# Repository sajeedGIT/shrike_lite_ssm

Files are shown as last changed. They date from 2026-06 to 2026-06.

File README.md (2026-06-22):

# Shrike 

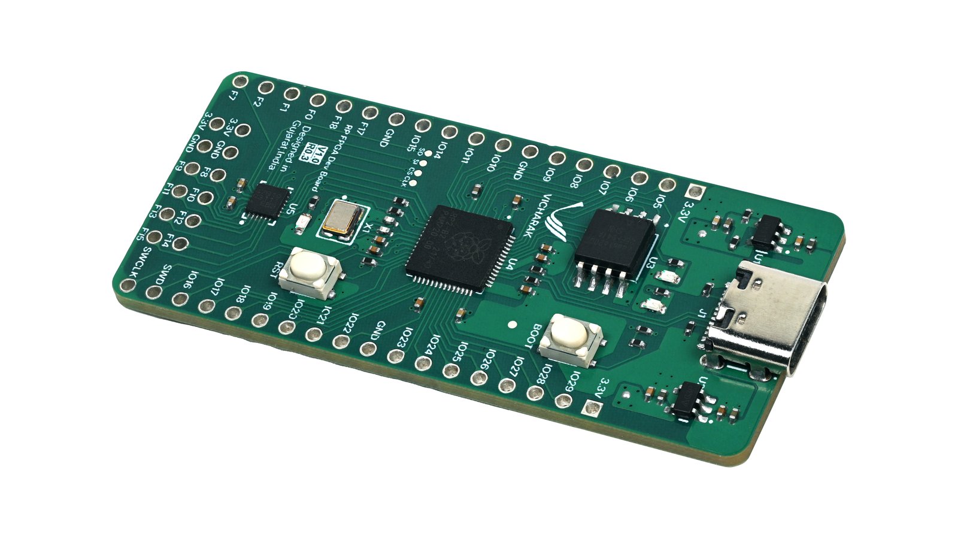
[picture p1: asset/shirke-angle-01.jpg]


Shrike is a family of low cost affordable FPGA development board along with a host microcontroller. 
Currently the family features these two members -: 

1. Shrike-lite (FPGA with RP2040) 
2. Shrike      (FPGA with RP2350)
3. Shrike-fi   (FPGA with ESP32-S3) 

And a lot version under development.

We usually work on very complex FPGA-based projects built around [Vaaman](https://vicharak.in/vaaman) and its upcoming series. However, Shrike is a passion project at Vicharak, driven by our love for engineering across both embedded microcontrollers and FPGAs.

Our goal is to make FPGAs accessible to everyone by offering robust toolchains, high-quality hardware, and strong ecosystem support. We’re committed to keeping the hardware prices extremely low, and every piece of software for Shrike will be completely open-source.

We at vicharak have kept in mind need of a learner, maker and a hobbyist while designing this art. This dev board will be your stepping stone in the field of FPGA, reconfigurable and heterogenous computing.

We invite contributors from all over the world to join us in this mission. Together, let’s make FPGA technology truly accessible to all. 

### Get the Hardware 

Shrike-lite the RP2040 version of the family is available at our store for worldwide shipping and the Shrike RP2350 version will be available on the crowdsupply soon. You can follow the links below to get both.

#### 1. [Shrike-lite](https://store.vicharak.in/?product=shrike&post_type=product&name=shrike&v=13b5bfe96f3e)

#### 2. [Shrike](https://www.crowdsupply.com/vicharak/shrike)

#### 3. [Shrike-fi](https://store.vicharak.in/?product=v002743)

### Board level Block Diagram

<div align="center">

shrike

</div>

### Key Features : 

| **Feature** | **Shrike** | **Shrike-lite** |**Shrike-fi** |
|:---:|:---:|:---:|:---:|
| FPGA | 1120 × 5-input LUTs | 1120 × 5-input LUTs | 1120 × 5-input LUTs|
| MCU | RP2350 | RP2040 | ESP32-S3 |
| PMOD Compatible Connector | ✅ | ✅ | ✅ |
| Breadboard Compatible | ✅ | ✅ | ✅ |
| FPGA ↔ MCU IO Interface | ✅ | ✅ | ✅ |  
| Flash (QSPI) | 4 MB | 4 MB | 8 MB |
| User LEDs | 2 | 2 | 2 |
| USB Type-C (Power & Programming) | ✅ | ✅ | ✅ |
| WiFi | ❌ | ❌ | ✅ |
| BLE | ❌ | ❌ | ✅ |
| Optional Add-on Features |
| PSRAM (QSPI) ( Optional ) | ❌ | ❌ | Upto 8 MB |
| BMS On Board ( Optional ) | ❌ | ❌ | ✅ | 

#### **Note**

The optional add on for the Shrike-fi are not soldered in the base version , board version with these part soldered will be launched at later date.
However you can solder them yourself in the base version as well read more [here](https://vicharak-in.github.io/shrike/hardware_overview.html#shrike-hardware-overview).

### Check out 
 1. [Documentation](https://vicharak-in.github.io/shrike/index.html)
 2. [Pin_outs](https://vicharak-in.github.io/shrike/shrike_pinouts.html)
 3. [FPGA_CPU_Interconnect](https://vicharak-in.github.io/shrike/shrike_pinouts.html#fpga-rp2040-communication-pin-outs)

## 📫 Join our communities at :
  
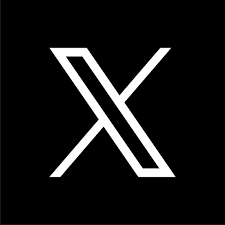
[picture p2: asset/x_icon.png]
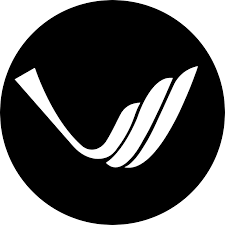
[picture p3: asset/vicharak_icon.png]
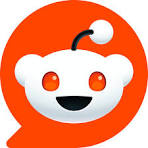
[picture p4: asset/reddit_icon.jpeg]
   [](https://discord.com/invite/EhQy97CQ9G)  &nbsp; [](https://x.com/Vicharak_In)  &nbsp; [](https://discuss.vicharak.in/)  &nbsp; [](https://www.linkedin.com/company/vicharak-in)  &nbsp; [](https://www.reddit.com/r/Vicharak/)  &nbsp;

### Note
 
We are building a ecosystem for learners , makers and hobbyist around shrike and the projects that will follow in future, thus we request you contribution in the same. Join our communities across all the platforms, pitch and showcase your ideas with Shrike. 

Thank You 

## Contribution Guideline  

Your contribution to the Shrike project are always welcome.
To contribute fork the project test your changes and create a PR. Few things in to keep in mind for better contribution. 
Please read the Contribution [Guide](./CONTRIBUTING.md) to know them.

### What to contribute ? 

You can contribute the project's and example's that you have designed on Shrike or any utils that you might have designed.

We also have live bounty from time to time check it [here](./bounty.md) 

## LICENSE 

### Software

This project’s software is licensed under the GNU General Public License v2.0 (GPL-2.0).
See the [LICENSE](./LICENSE.md)for details.

### Hardware

This project’s hardware designs (HDL/RTL, schematics, PCB files, constraints, etc.) are licensed under the CERN Open Hardware License v1.2.
See [LICENSE_HW](./LICENSE_HW.md) for details.

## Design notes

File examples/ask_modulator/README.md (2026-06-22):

# ask_modulator

**Difficulty:** Advanced

**Uses MCU:** Yes

**External Hardware:** RC Filter (1 kΩ Resistor, 10 nF Capacitor), Oscilloscope (optional)

## Overview

This example implements a mixed-signal Digital-to-Analog communication system using the Shrike board. The FPGA generates a sine wave using Direct Digital Synthesis (DDS), converts it into a PWM signal, and modulates it using Amplitude Shift Keying (ASK) controlled by the RP2040. You will learn DDS, PWM-based DAC techniques, and FPGA–MCU co-design for communication systems.

## Compatibility

| Board | Firmware | Status |
| --- | --- | --- |
| Shrike-Lite (RP2040) | `firmware/micropython/` | ✅ Tested |
| Shrike (RP2350) | `firmware/micropython/` | ✅ Tested |
| Shrike-fi (ESP32-S3) | `firmware/micropython/` | ⬜ Untested |

> FPGA bitstream is the same across all boards.

## Hardware Setup

### RC Filter (Required for Analog Output)

The FPGA outputs a high-frequency PWM signal. An RC low-pass filter is required to reconstruct the analog sine wave.

* Resistor: 1 kΩ
* Capacitor: 10 nF (Code 103)
* Cutoff Frequency: ~15.9 kHz

**Connection:**

* FPGA Output → Resistor → Output Node
* Capacitor from Output Node → Ground
* Probe at Output Node

### Pin Connections

| Signal | RP2040 Pin | FPGA Pin (Board Label) | Physical Pin |
| --- | --- | --- | --- |
| Freq Bit 0 (LSB) | GPIO 5 | FPGA_IO1 | PIN 14 |
| Freq Bit 1 | GPIO 6 | FPGA_IO2 | PIN 15 |
| Freq Bit 2 | GPIO 7 | FPGA_IO17 | PIN 8 |
| Freq Bit 3 | GPIO 8 | FPGA_IO18 | PIN 9 |
| Freq Bit 4 | GPIO 9 | FPGA_IO8 | PIN 23 |
| Freq Bit 5 (MSB) | GPIO 10 | FPGA_IO9 | PIN 24 |
| Data / Enable | GPIO 16 | FPGA_IO0 | PIN 13 |
| PWM Output | — | FPGA_IO14 | PIN 5 |

> Ensure common ground between RP2040 and FPGA.

## Quick Start (Pre-Built Bitstream)

1. Generate and upload the FPGA bitstream
2. Copy `flash.py` and `helloshrike.py` to the RP2040
3. Run `flash.py` once to configure FPGA
4. Run `helloshrike.py`
5. Observe PWM output on FPGA_IO14 using an oscilloscope

Expected result: Bursts of sine waves representing transmitted data using ASK modulation

## Build From Source

### FPGA (Verilog)

1. Open project in Go Configure Software Hub
2. Select FPGA part `SLG47910V (Rev BB)`
3. Paste Verilog into `main.v`
4. Configure I/O Planner and generate bitstream

### Firmware (MicroPython)

1. Open `flash.py` and `helloshrike.py` in Thonny
2. Upload to RP2040
3. Run scripts

## How It Works

The FPGA implements a DDS-based signal generator with three main components:

1. **Phase Accumulator:**
   A 16-bit counter incremented by a tuning word each clock cycle. This determines output frequency.

2. **Sine LUT:**
   A 64-entry lookup table mapping phase to amplitude (0–63), generating a sine waveform.

3. **PWM Generator:**
   Converts amplitude into a 1-bit PWM signal (~781 kHz switching frequency).

ASK modulation is applied at output:

* `i_data = 1` → sine wave transmitted
* `i_data = 0` → output forced to zero

The RP2040:

* Sends frequency tuning word (6-bit parallel bus)
* Controls modulation signal
* Encodes characters using a custom 6-bit encoding scheme

### Key Equations

* PWM Frequency:
  `50 MHz / 64 ≈ 781.25 kHz`

* Output Frequency:
  `F_out = (F_clk × TW) / 2^16`

* Example:
  `TW = 1 → ~762 Hz`

## Expected Output

### Oscilloscope Output

* Logic 1 → Sine wave (~3V peak)
* Logic 0 → Flat line (0V)

Signal appears as bursts of sine waves separated by silence.

### Terminal Output

```
--- Transmitting: HelloShrike123 ---
Sending 'H' -> Code 01 -> 000001
Sending 'e' -> Code 02 -> 000010
Sending 'l' -> Code 03 -> 000011
Sending 'l' -> Code 03 -> 000011
Sending 'o' -> Code 04 -> 000100
Sending 'S' -> Code 05 -> 000101
Sending 'h' -> Code 06 -> 000110
Sending 'r' -> Code 07 -> 000111
Sending 'i' -> Code 08 -> 001000
Sending 'k' -> Code 09 -> 001001
Sending 'e' -> Code 02 -> 000010
Sending '1' -> Code 51 -> 110011
Sending '2' -> Code 52 -> 110100
Sending '3' -> Code 53 -> 110101
```

The waveform corresponds to encoded binary data transmitted via ASK.

## Notes

* Noise on FPGA GPIO inputs may be interpreted as logic high
* External pull-ups are not strictly required in this setup
* Full ASCII support can be implemented by extending encoding (exercise for user)

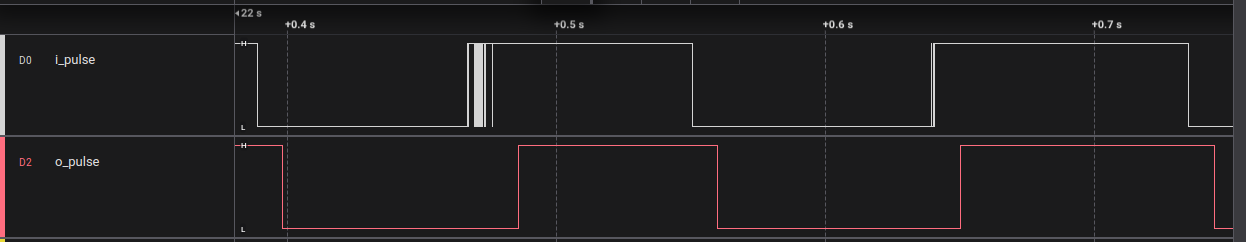
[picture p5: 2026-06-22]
examples/button_debouncer/ffpga/images/debouncer_output.png

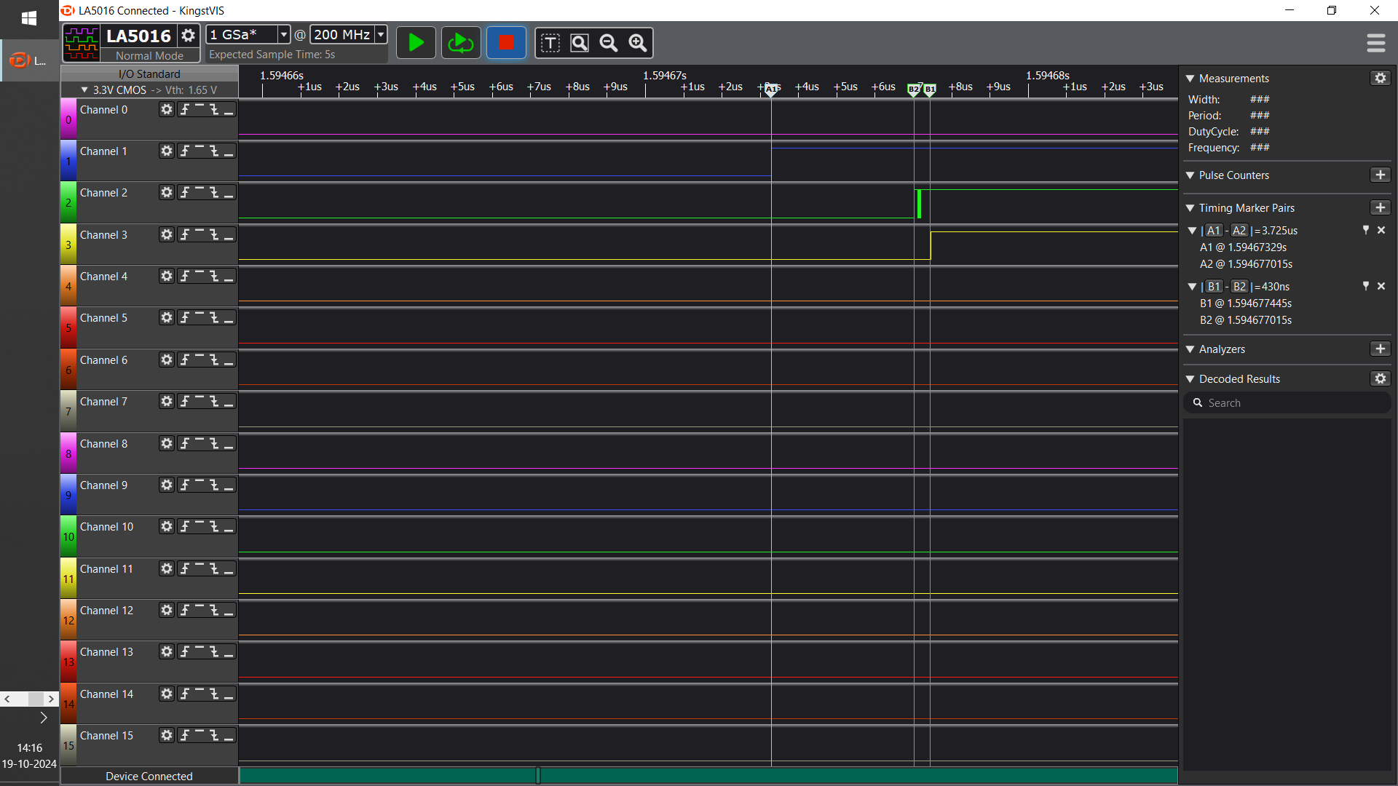
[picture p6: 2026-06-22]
docs/images/Screenshot (1320).png

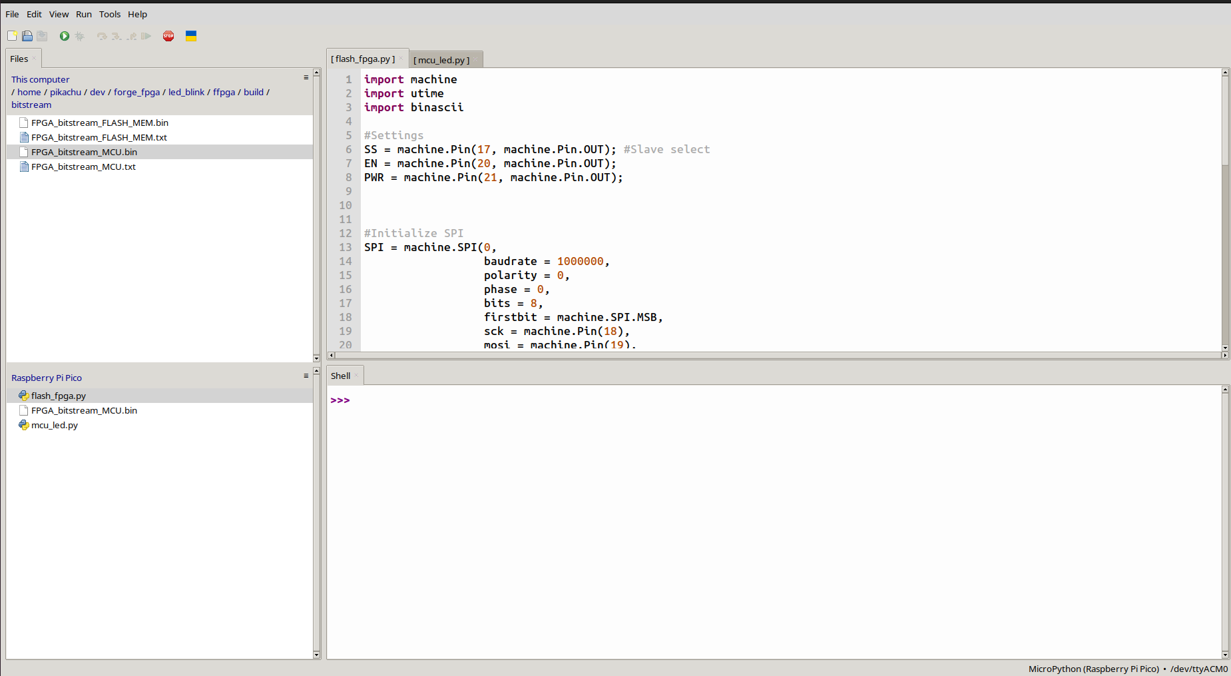
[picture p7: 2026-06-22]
docs/images/file_view.png

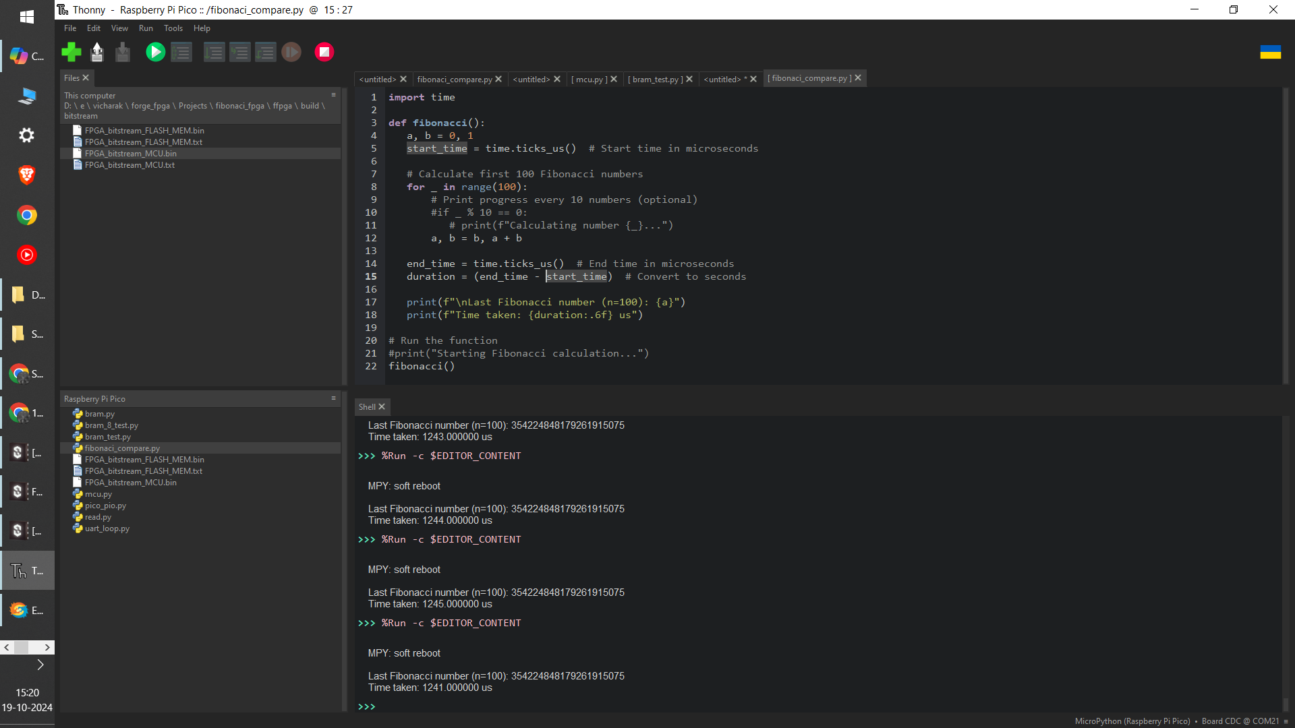
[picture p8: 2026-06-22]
docs/images/image.png

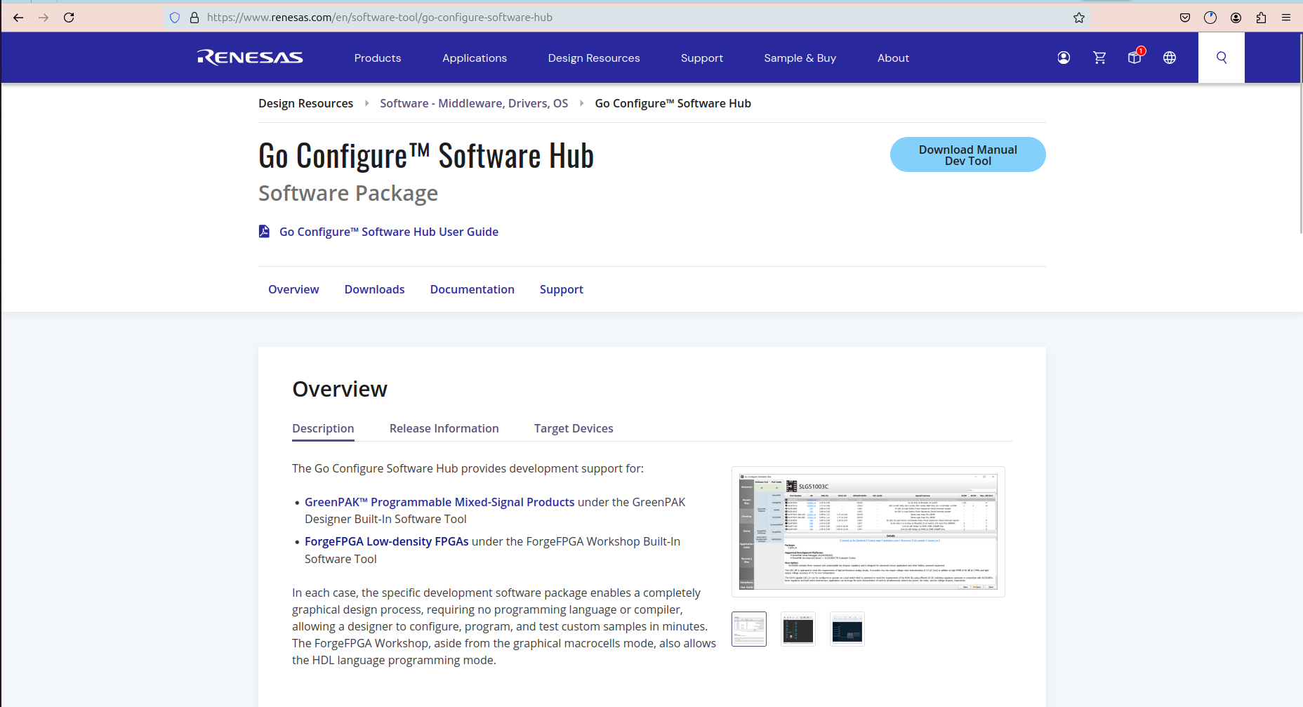
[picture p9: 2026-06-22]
docs/images/software.png

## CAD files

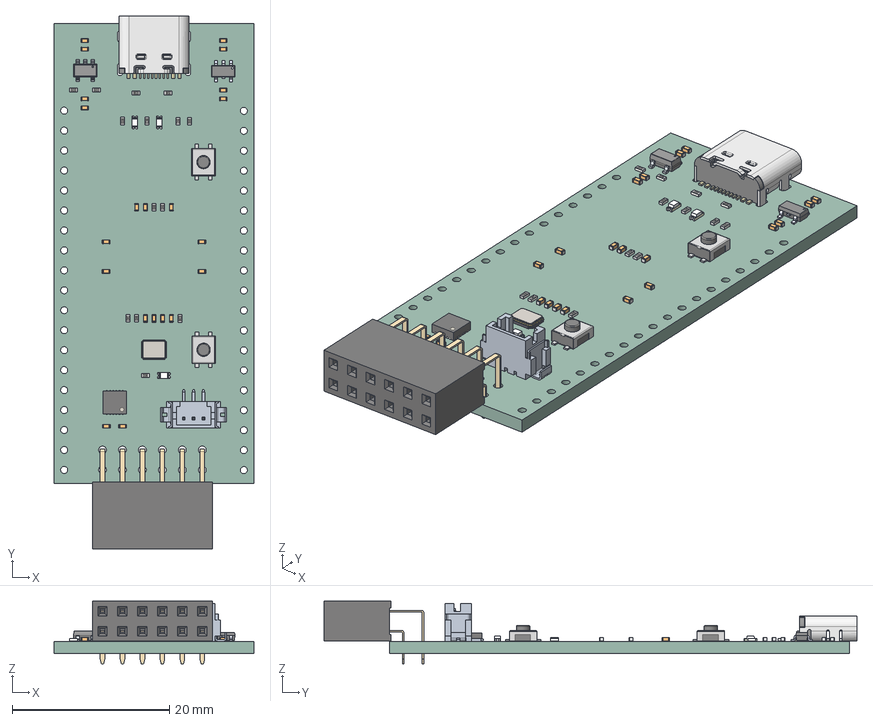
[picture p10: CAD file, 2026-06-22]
hardware/shrike-lite/kicad/v1_r0.4/Shrike-lite.step
25.4 x 67.8 x 7.98 mm
kicad_embedded_BCDEFA549BD92648B89B079BD65F0360 x 3
kicad_embedded_4BF2C315065B03F2EDB6664BF6E06EBC x 14
PinsArrayL
PinsArrayR
Shrike-lite 1.18.1
kicad_embedded_23D3BBCB113E4F12280F49A9A7372AAE
kicad_embedded_5DA03CE9F3160850AF560ED0F9C2898B
kicad_embedded_72BB9CE2D1522D823768491D5397E6AB x 2
kicad_embedded_29C47ED5F14A361E81E1A38E2F171F89
kicad_embedded_BBED6F8B535C06F9EA1D5AD73DD78B29
ConPins
PcbPins
Mold
Frame
Shrike-lite_PCB

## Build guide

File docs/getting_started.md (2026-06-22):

(getting_started)=

# Getting Started

In this getting started guide we will see how to blink an led on shrike both on fpga and MCU.

You can program the microcontroller on Shrike using three methods:<br>

&emsp;**1. Arduino (C/C++)**  
&emsp;**2. MicroPython**
&emsp;**3. Circuit-Python**

All are beginner-friendly, and you can switch between them anytime.  

Let's follow the steps and get Shrike up and running!

:::::::{tab-set}

::::::{tab-item} ArduinoIDE

# Shrike with ArduinoIDE

If you already know Arduino and love working with the Arduino IDE, you can continue using it with Shrike. You do not have to switch to MicroPython unless you want to.

We will follow these steps to setup our arduino IDE for shrike. If you don't have arduino IDE already ,you can download it from [here](https://www.arduino.cc/en/software/) or if you are using linux(ubuntu)then just run 
```
sudo apt install arduino
```

### Step 1. Adding the board support for Shrike

The Shrike has a on board RP2040/RP2350/ESP32-S3 has a host controller the Arduino IDE doesn't native support them however we can add the board support for the same.

It is quit straight forward we need to add this URL in the addition board URL section of arduino IDE which you can find in File->Preferences.

:::::{tab-set}

::::{tab-item} Shrike/Shrike-lite
:sync: Shrike/Shrike-lite

```
https://github.com/earlephilhower/arduino-pico/releases/download/global/package_rp2040_index.json
``` 

::::

::::{tab-item} Shrike-fi
:sync: Shrike-fi

```
https://raw.githubusercontent.com/espressif/arduino-esp32/gh-pages/package_esp32_index.json
``` 

::::

:::::

If you already have another board URL just add a "," between the two URL's.

<div align="center">

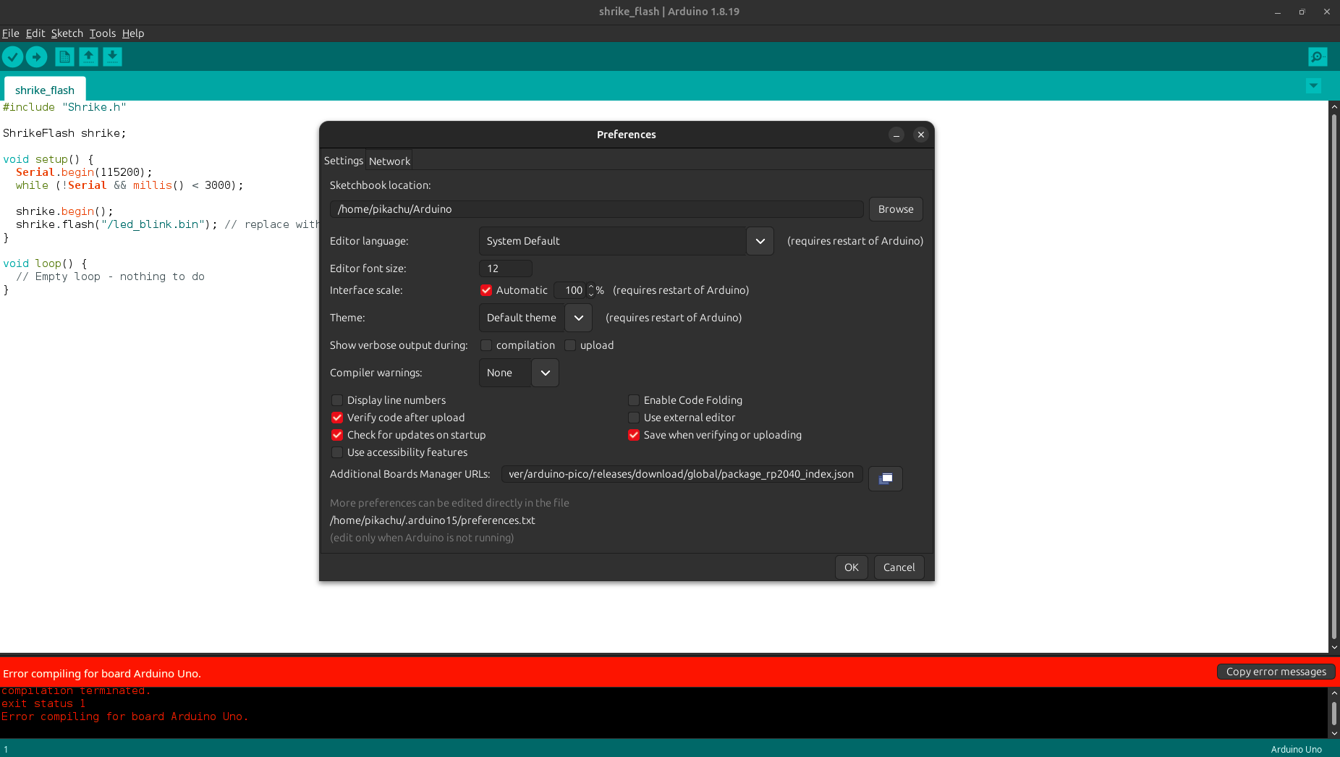
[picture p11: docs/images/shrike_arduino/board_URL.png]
ADD BOARD URL
 

</div>

These board support had been created by [earlephilhower](https://github.com/earlephilhower) and you can check out github [repository](https://github.com/earlephilhower/arduino-pico) for more details.

After adding the URL go to Tools->Boards->Board Manager in the Arduino IDE. 

:::::{tab-set}

::::{tab-item} Shrike/Shrike-lite
:sync: Shrike/Shrike-lite

Then search for pico and the board from Earle F. Philhower. 

<div align="center">

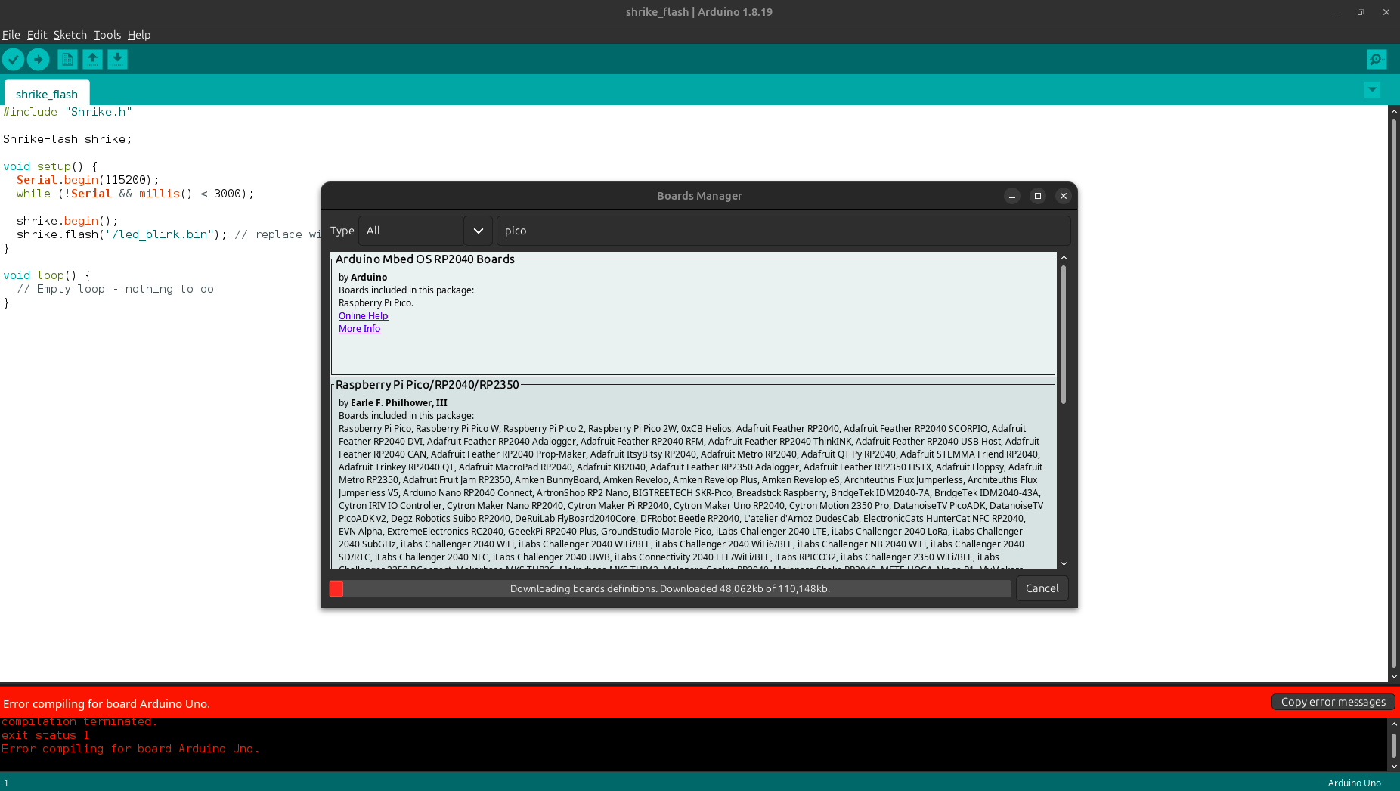
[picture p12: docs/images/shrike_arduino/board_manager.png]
ADD BOARD
 

</div>

::::

::::{tab-item} Shrike-fi
:sync: Shrike-fi

Then search for ESP32 by Espressif Systems.

<!-- TODO: Add board manager image for ESP32. -->

::::

:::::

Perfect we have successfully add the board support for the Shrike.

As we discussed earlier, in Shrike the micro-controller (RP/ESP32) is responsible for configuring the FPGA.  

To make this possible, we developed a simple mechanism: we store the FPGA bit-streams in the MCU's flash memory and retrieve them whenever we need to configure the FPGA. To do this we will need to use a file system called littleFS.

### Step 2. Adding the LittleFS Tool

The LittleFS library in Arduino allows you to store, load, and update the bitstream in the flash memory through the microcontroller.

We need to add a Little-FS utility to bind a bin file (FPGA bitstream with code for Shrike). We can find the utility [here](https://github.com/earlephilhower/arduino-littlefs-upload/releases) download the latest release ZIP. 

Now for setting up these tools for Arduino IDE version 2.x.x please follow [this](https://randomnerdtutorials.com/arduino-ide-2-install-esp32-littlefs/) guide and after proper setup please continue the below steps. 

This works for both the RP2040 and ESP32-S3 based boards. ( even tho name says esp32).

You will need to restart the Arduino IDE and you should see the Little FS tool like this in your Tools menu.

<!-- TODO: Update this image. -->

For more details on the LittleFS tool checkout this [repository](https://github.com/earlephilhower/arduino-littlefs-upload).

### Step 3. Installing the Shrike Library 

The Arduino library developed by Vicharak takes care of configuring the FPGA for you. You can install it directly from the Arduino IDE's Library Manager, just search for **"Shrike"** and install the **Shrike** library.

<!-- TODO: Update this image --> 

<div align="center">

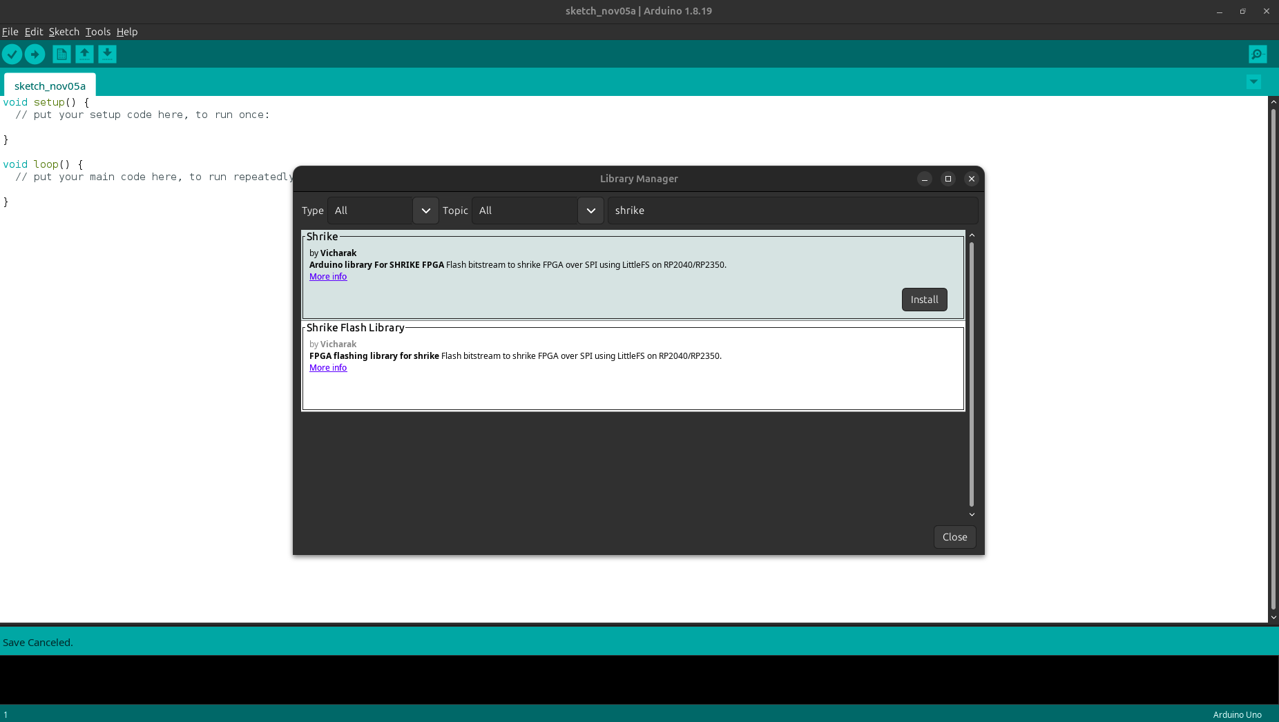
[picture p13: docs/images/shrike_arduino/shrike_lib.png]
ADD SHRIKE lib
 

</div>

We are almost done with the setup lets continue and blink en led on FPGA using the arduino IDE. 

### Step 4. Programming the FPGA from ArduinoIDE

Lets program out first bitstream to fpga using the arduino. We will be blinking an led.

Start Arduino IDE and look for Shrike -> shrike_flash in the example section of IDE and then save it with a name of your choice and at a location of your choice. This will create a folder with the name, now in the folder/dir create a subfolder by name `data` keep the case in mind. 

Any bitstream that needs to be uploaded to the board should be placed in the folder. 
We have already generated and hosted a bitstream to blink led [here](https://github.com/vicharak-in/shrike/blob/main/test/bitstreams/v1_4/led_blink.bin) save this bitstream to the data subfolder.

Checkout guide to learn how to generate your own fpga design [here](./generating_your_first_bitstream.md).

Once you have done this, open Arduino IDE and click on Compile. The compilation should complete without any errors. If you encounter any errors, don't worry,we have a Discord community. Hop in there and we'll help you out or you can always use claude or chatgpt.

If the compilation has been done without any error then it's time to connect the board in boot mode " PRESS THE BOOT BUTTON WHILE CONNECTING THE BOARD WITH PC" ( this should be done only the first time of setting up if arduino are if you have programmed the board with any other way last time).

:::::{tab-set}

::::{tab-item} Shrike/Shrike-lite
:sync: Shrike/Shrike-lite

In the tools section select the Board as VICHARAK Shrike Lite / VICHARAK Shrike based on your board version and flash size as 4MB Sketch:2MB and FS:2MB and CPU Speed as 125 Mhz. 

::::

::::{tab-item} Shrike-fi
:sync: Shrike-fi

In the tools section select the Board as Generic ESP32-S3 based on your board version and flash size as 8MB Sketch:4MB and FS:4MB . 

::::

:::::
Now you need to upload the file system to the board to do so press `ctrl+shift+p` you will see the drop down menu.

Search for Build LittleFS command and run it. 

After that in the same menu look for Upload LittleFS command and run that too. 

If both of these options are executed properly then then hit upload. 

You should see the beautiful blue led blinking on board.

Congratulation you have your arduino IDE and shrike ready to be programmed using the Arduino infrastructure. 

> Credit and Gratitude to [earlephilhower](https://github.com/earlephilhower/) for creating the board support for RP2040/RP2350 in ArduinoIDE and the little FS tool. 

<!-- 
For shrike Lite

:::::{tab-set}

::::{tab-item} Shrike/Shrike-lite
:sync: Shrike/Shrike-lite

Blehhhh Shrike-lite

::::

::::{tab-item} Shrike-fi
:sync: Shrike-fi

Blehh Shrike-fi

::::

:::::

-->

::::::

::::::{tab-item} Micro-python 

# Shrike with Micro-python 

We have created custom binary for shrike this contains a shrike.py library that has custom function to flash fpga and few other functions as well.

### 1. Uploading the shrike binary

:::::{tab-set}

::::{tab-item} Shrike/Shrike-lite
:sync: Shrike/Shrike-lite

1. Download the binary corresponding to your board version from the shrike's [Releases](https://github.com/vicharak-in/shrike/releases/)
2. Hold the boot button on the board and connect it the your pc now shrike will show up as as storage device.
3. Copy the downloaded uf2 in storage device you can simply drag and drop in mostly all the devices. 
4. After the successful copying the storage device should disappear.

Check the video tutorial on how to upload the uf2 Shrike dev board(its a generic board video and uf2 will differ in our case) [here](https://www.youtube.com/watch?v=os4mv_8jWfU).

Congratulations you have successfully uploaded the uf2. 

#### Shrike Mass Storage Device 

Onces that you have copied the uf2 to the Shrike.  The board will disconnect momentary and so up as both a mass storage device and tty/ACM device now the mass storage is the part where you would need to save you bitstream (read step 3). 

The default device ID for mass storage device is `5221-0000` this could be changed as per your choice. 
For windows simply right click and rename for changing the name in linux read [this](https://superuser.com/questions/223527/renaming-a-fat16-volume). 

::::

::::{tab-item} Shrike-fi
:sync: Shrike-fi

1. Download the binary corresponding to your board version from the shrike's [Releases](https://github.com/vicharak-in/shrike/releases/).

2. Install the ESP tools `pip install esptool`. 
    You might need to activate a python virtual environment. Check this guide to know how to do so. 

3. Then execute  this command `python -m esptool erase_flash`

4. And Flash the binary to ESP32-S3 using this command 

```
python -m esptool --chip esp32s3 -b 460800 --before default_reset --after hard_reset write_flash --flash_mode dio --flash_size 4MB --flash_freq 80m 0x0 firmware.bin
```

---

Congratulations you have successfully uploaded the binary. 

::::

:::::

### 2. Get the bitstream(.bin) for led blink 

To program a FPGA you will require  bitstream file this is much like a firmware for MCU's we will see how to generate these but for now we have uploaded the bitstream required for led_bin you can download them the corresponding to your board's version [here](https://github.com/vicharak-in/shrike/tree/main/test/bitstreams). 

Now that you have both uf2 and bin file settled up lets move forward and upload the bitstream to board.

### 3. Getting the Thonny IDE 

The bitstream can be uploaded on the shrike using one of these two ways 
   1. Using a GUI Based-IDE (Thonny)
   2. Using Command line interface (CLI)

In this guide we will use Thonny however guide to programme using CLI can be found [here](./shrike_cli_guide.md).

Now we will need to get thonny on our pc. Installation is quite straight forward You can download it from [here](https://thonny.org/). 

Now that we have got all the required tools set-ed up let blink some leds.

Open thonny and connect the board to the laptop (do not press boot button this time). And do these two things 
   1. Connect the board from the bottom right corner of Thonny IDE.
   2. Go to file view mode in the thonny to see the RP2350/RP2040 as a file system.

### 4. Flashing the bitstream 

You should in thonny see both the your pc and Shrike file's on the left windows now we have to transfer the led_blink.bin file to the Shrike. 
To do so find the file on your system then right click and upload.

Now we will have to flash this file to the fpga to do so we will use the function 

```
    shrike.flash("<your_bitstream_name>.bin")
```

:::{note}

For any custom project the bitstream file that you need to copy will be named as "FPGA_bitstream_MCU.bin" found in fpga -> build -> bitstream folder in your project directory.  
If you copy any other file present in the bitstream folder the fpga wont be programmed.
You are free to change the name of this file however you please.

:::

In thonny open a new python file and write this python script 

```
    import shrike
    shrike.flash("led_blink.bin")
```

Save this file to your board and run it. (to run this file on board boot up just name it as main.py)

::::::

::::::{tab-item} Circuit-Python 

# Shrike with Circuit Python

CircuitPython is a programming language designed by adafruit to simplify experimenting and learning to code on low-cost microcontroller boards. It build on a fork of Micropython , thus its seems very similar yet very different.

The way Circuit-Python works with Shrike is we have a custom circuit python build (binary). One must follow these steps to get started with the Circuit-Python on Shrike.

### 1. Uploading the Shrike binary

1. Download the binary corresponding to your board version from the shrike's [Release](https://github.com/vicharak-in/shrike/releases/).
2. Hold the boot button on the board and connect it the your pc now shrike will show up as as storage device.
3. Copy the downloaded uf2 in storage device you can simply drag and drop in mostly all the devices. 
4. After the successful copying the storage device should disappear.

Check the video tutorial on how to upload the uf2 Shrike dev board(its a generic board video and uf2 will differ in our case) [here](https://www.youtube.com/watch?v=os4mv_8jWfU).

Congratulations you have successfully uploaded the Circuit-Python uf2. 

### 2. Get the bitstream(.bin) for led blink 

To program a FPGA you will require  bitstream file this is much like a firmware for MCU's we will see how to generate these but for now we have uploaded the bitstream required for led_bin you can download them the corresponding to your board's version [here](https://github.com/vicharak-in/shrike/tree/main/test/bitstreams). 

Now that you have both uf2 and bin file settled up lets move forward and upload the bitstream to board.

The board will showing up as a storage device on the pc now copy the downloaded bitstream to the board. 

### 3. Getting the Thonny IDE 

Now we will need to get thonny on our pc. Installation is quite straight forward You can download it from [here](https://thonny.org/). 

Now that we have got all the required tools set-ed up let blink some leds.

Open thonny and connect the board to the laptop (do not press boot button this time). And connect the board from the bottom right corner of Thonny IDE.

### 4. Flashing the bitstream 

The custom binary of circuit-python contain a python library for flashing and resting  the fpga and a few other functions as well. 

So we will use this library to flash this bitstream file to the fpga, to do so we will use the function 

```
    shrike.flash("<your_bitstream_name>.bin")
```

If you are using the test bitstream provided by use it is named as led_blink.bin 

:::{note}

For any custom project the bitstream file that you need to copy will be named as "FPGA_bitstream_MCU.bin" found in fpga -> build -> bitstream folder in your project directory.  
If you copy any other file present in the bitstream folder the fpga wont be programmed.
You are free to change the name of this file however you please.

:::

In thonny open a new python file and write this python script 

```
    import shrike
    shrike.flash("led_blink.bin")
```

Save this file to your board and run it. (to run this file on board boot up just name it as main.py)

::::::

:::::::

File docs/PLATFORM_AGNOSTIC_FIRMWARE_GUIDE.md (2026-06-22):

# Writing Platform-Agnostic Firmware for Shrike

This guide explains how to write a single firmware source file that runs on all boards in the Shrike family — Shrike-Lite (RP2040), Shrike (RP2350), and Shrike-fi (ESP32-S3) — without maintaining separate codebases.

The FPGA side is identical across all boards (same SLG47910 ForgeFPGA, same bitstream). Only the host MCU changes. This guide covers how to handle those MCU differences cleanly.

---

## The Problem

Each board in the Shrike family uses a different host MCU:

| Board | MCU | Arduino Core | MicroPython Platform |
|---|-----|---|---|
| Shrike-Lite | RP2040 | `arduino-pico` (Earle Philhower) | `rp2` |
| Shrike | RP2350 | `arduino-pico` (Earle Philhower) | `rp2` |
| Shrike-fi | ESP32-S3 | `arduino-esp32` (Espressif) | `esp32` |

The differences typically fall into three categories:

1. **Pin assignments** — Different GPIOs for the FPGA interconnect, SPI, UART
2. **Peripheral initialization** — Different SPI class instances, UART ports
3. **Platform APIs** — Filesystem, Wi-Fi (ESP32 only), deep sleep, etc.

The goal is to isolate these differences into a small, clearly marked section at the top of each file, while keeping the core application logic shared.

---

## Arduino IDE — Using `#ifdef`

### How It Works

The Arduino build system defines architecture macros at compile time based on the selected board. These macros let you conditionally compile different code blocks.

| Board Selected | Macro Defined |
|---|---|
| Any RP2040 board | `ARDUINO_ARCH_RP2040` |
| Any RP2350 board | `ARDUINO_ARCH_RP2040` (same core) |
| Any ESP32 board | `ARDUINO_ARCH_ESP32` |

> **Note:** RP2350 uses the same `arduino-pico` core as RP2040 and defines the
> same `ARDUINO_ARCH_RP2040` macro. If you ever need to distinguish between
> RP2040 and RP2350 specifically, check for `PICO_RP2350` which is defined
> only on RP2350 builds.

### Pattern 1 — Pin Definition Block

The simplest and most common case. Put all pin definitions in a single block at the top.

```cpp
// =============================================================
// Platform Configuration
// =============================================================

#ifdef ARDUINO_ARCH_RP2040
  // Shrike-Lite (RP2040) / Shrike (RP2350)
  #define FPGA_SPI_SS    1
  #define FPGA_SPI_SCK   2
  #define FPGA_SPI_MOSI  3
  #define FPGA_SPI_MISO  0
  #define FPGA_EN        13
  #define FPGA_PWR       12

  #define UART_TX_PIN    0
  #define UART_RX_PIN    1

#elif defined(ARDUINO_ARCH_ESP32)
  // Shrike-fi (ESP32-S3)
  #define FPGA_SPI_SS    10
  #define FPGA_SPI_SCK   12
  #define FPGA_SPI_MOSI  11
  #define FPGA_SPI_MISO  13
  #define FPGA_EN        5
  #define FPGA_PWR       4

  #define UART_TX_PIN    17
  #define UART_RX_PIN    18

#else
  #error "Unsupported board. Please use RP2040, RP2350, or ESP32-S3."
#endif

// =============================================================
// Application Code (shared across all platforms)
// =============================================================

void setup() {
  Serial.begin(115200);
  pinMode(INTER_0, INPUT);
  // ... rest of setup
}

void loop() {
  int val = digitalRead(INTER_0);
  // ... rest of application logic
}
```

**Key points:**
- The `#else #error` block catches unsupported boards at compile time
- All platform-specific code is contained in ONE block
- Everything after the block is 100% shared

### Pattern 2 — SPI Instance Handling

RP2040 and ESP32 initialize SPI differently. RP2040's default `SPI` object works fine, but ESP32 needs an explicit HSPI instance to avoid conflicts with its internal flash.

```cpp
#include <SPI.h>
#include <ShrikeFlash.h>

#ifdef ARDUINO_ARCH_RP2040
  // Default SPI works on RP2040/RP2350
  ShrikeFlash fpga;

#elif defined(ARDUINO_ARCH_ESP32)
  // ESP32 needs a dedicated HSPI instance
  SPIClass _hspi(HSPI);
  ShrikeFlash fpga(FPGA_EN, FPGA_PWR, FPGA_SPI_SS,
                   FPGA_SPI_SCK, FPGA_SPI_MOSI, FPGA_SPI_MISO);
#endif

void setup() {
  Serial.begin(115200);

  #ifdef ARDUINO_ARCH_ESP32
    _hspi.begin(FPGA_SPI_SCK, FPGA_SPI_MISO, FPGA_SPI_MOSI, FPGA_SPI_SS);
    fpga.begin(&_hspi);
  #else
    fpga.begin();
  #endif

  fpga.flash("/bitstream.bin");
}
```

> **Why HSPI?** ESP32's default SPI bus (VSPI) is often shared with internal
> flash. Using HSPI avoids the mutex crash that occurs when ShrikeFlash
> tries to access SPI while FreeRTOS is managing the flash bus.
> This was a real bug that was fixed during the ESP32 port of ShrikeFlash.

### Pattern 3 — Distinguishing RP2040 from RP2350

For most Shrike examples, RP2040 and RP2350 are interchangeable. But if you need to detect the specific chip (for example, to use RP2350-only features like extra GPIO or security functions):

```cpp
#ifdef ARDUINO_ARCH_RP2040
  #ifdef PICO_RP2350
    // RP2350-specific code
    #define MCU_NAME "RP2350"
  #else
    // RP2040-specific code
    #define MCU_NAME "RP2040"
  #endif
#elif defined(ARDUINO_ARCH_ESP32)
  #define MCU_NAME "ESP32-S3"
#endif

void setup() {
  Serial.begin(115200);
  Serial.print("Running on: ");
  Serial.println(MCU_NAME);
}
```

### Pattern 4 — Feature Flags for Optional Capabilities

ESP32-S3 has Wi-Fi and Bluetooth. RP2040/RP2350 don't. Use feature flags instead of scattering `#ifdef` throughout your code:

```cpp
// Feature detection
#ifdef ARDUINO_ARCH_ESP32
  #define HAS_WIFI       1
  #define HAS_BLUETOOTH  1
#else
  #define HAS_WIFI       0
  #define HAS_BLUETOOTH  0
#endif

void setup() {
  Serial.begin(115200);

  #if HAS_WIFI
    WiFi.begin("ssid", "password");
    Serial.println("Wi-Fi connecting...");
  #else
    Serial.println("Wi-Fi not available on this board");
  #endif
}
```

**Why feature flags?** They self-document what each platform can do. A contributor reading the code sees `HAS_WIFI` and immediately understands the intent, rather than parsing `ARDUINO_ARCH_ESP32` and guessing why it's there.

### Pattern 5 — Platform Abstraction Header (Advanced)

For complex examples with many platform differences, extract everything into a shared header:

```
firmware/
├── arduino-ide/
│   ├── uart_sum.ino
│   └── shrike_platform.h
```

**shrike_platform.h:**
```cpp
#ifndef SHRIKE_PLATFORM_H
#define SHRIKE_PLATFORM_H

#ifdef ARDUINO_ARCH_RP2040
  #define PLATFORM_NAME     "RP2040"
  #define FPGA_SPI_SS       1
  #define FPGA_SPI_SCK      2
  #define FPGA_SPI_MOSI     3
  #define FPGA_SPI_MISO     0
  #define FPGA_EN           13
  #define FPGA_PWR          12
  #define HAS_WIFI          0
  #define HAS_BLUETOOTH     0

#elif defined(ARDUINO_ARCH_ESP32)
  #define PLATFORM_NAME     "ESP32-S3"
  #define FPGA_SPI_SS       10
  #define FPGA_SPI_SCK      12
  #define FPGA_SPI_MOSI     11
  #define FPGA_SPI_MISO     13
  #define FPGA_EN           5
  #define FPGA_PWR          4
  #define HAS_WIFI          1
  #define HAS_BLUETOOTH     1

#else
  #error "Unsupported board"
#endif

#endif // SHRIKE_PLATFORM_H
```

**uart_sum.ino:**
```cpp
#include "shrike_platform.h"
#include <ShrikeFlash.h>

// Clean application code — no #ifdefs needed here
void setup() {
  Serial.begin(115200);
  Serial.print("Shrike running on: ");
  Serial.println(PLATFORM_NAME);

  pinMode(INTER_0, OUTPUT);
  // ...
}
```

> **When to use this:** If your `#ifdef` block exceeds ~20 lines in the main
> sketch, extract it into a header. For simple examples (pin changes only),
> keep it inline — the header adds a file without adding clarity.

---

## MicroPython — Using `sys.platform`

### How It Works

MicroPython doesn't have a preprocessor. Instead, you detect the platform at runtime using `sys.platform`:

| Board | `sys.platform` |
|---|---|
| Shrike-Lite (RP2040) | `'rp2'` |
| Shrike (RP2350) | `'rp2'` |
| Shrike-fi (ESP32-S3) | `'esp32'` |

### Pattern 1 — Pin Configuration Dict

```python
import sys
from machine import Pin, UART, SPI

# =============================================================
# Platform Configuration
# =============================================================

if sys.platform == 'rp2':
    CONFIG = {
        'platform':      'RP2040/RP2350',
        'fpga_spi_ss':   1,
        'fpga_spi_sck':  2,
        'fpga_spi_mosi': 3,
        'fpga_spi_miso': 0,
        'fpga_en':       13,
        'fpga_pwr':      12,
        'uart_id':       0,
        'uart_tx':       0,
        'uart_rx':       1,
        'interconnect':  [6, 7, 8, 9, 10, 11],
    }

elif sys.platform == 'esp32':
    CONFIG = {
        'platform':      'ESP32-S3',
        'fpga_spi_ss':   10,
        'fpga_spi_sck':  12,
        'fpga_spi_mosi': 11,
        'fpga_spi_miso': 13,
        'fpga_en':       5,
        'fpga_pwr':      4,
        'uart_id':       1,
        'uart_tx':       17,
        'uart_rx':       18,
        'interconnect':  [35, 36, 37, 38, 39, 40],
    }

else:
    raise RuntimeError(f"Unsupported platform: {sys.platform}")

# =============================================================
# Application Code (shared)
# =============================================================

print(f"Running on {CONFIG['platform']}")

uart = UART(CONFIG['uart_id'],
            baudrate=115200,
            tx=Pin(CONFIG['uart_tx']),
            rx=Pin(CONFIG['uart_rx']))

inter_pins = [Pin(p, Pin.IN) for p in CONFIG['interconnect']]
```

**Why a dict?** Cleaner than loose variables. You can pass `CONFIG` to functions, print it for debugging, or serialize it. It also keeps the platform block visually contained.

### Pattern 2 — UART Initialization Differences

RP2040 and ESP32 handle UART slightly differently:

```python
import sys
from machine import UART, Pin

if sys.platform == 'rp2':
    # RP2040: UART 0 with explicit pin assignment
    uart = UART(0, baudrate=115200, tx=Pin(0), rx=Pin(1))

elif sys.platform == 'esp32':
    # ESP32: UART 1 (UART 0 is reserved for REPL)
    uart = UART(1, baudrate=115200, tx=Pin(17), rx=Pin(18))

# Shared logic — works with either uart object
def send_command(cmd):
    uart.write(cmd.encode())

def read_response():
    if uart.any():
        return uart.read()
    return None
```

> **ESP32 UART note:** UART 0 on ESP32 is typically connected to the USB-REPL.
> Always use UART 1 or UART 2 for FPGA communication on Shrike-fi.

### Pattern 3 — SPI for FPGA Bitstream Flashing

```python
import sys
from machine import SPI, Pin
import time

if sys.platform == 'rp2':
    spi = SPI(0,
              baudrate=8_000_000,
              polarity=0,
              phase=0,
              sck=Pin(2),
              mosi=Pin(3),
              miso=Pin(0))
    ss  = Pin(1, Pin.OUT, value=1)
    en  = Pin(13, Pin.OUT)
    pwr = Pin(12, Pin.OUT)

elif sys.platform == 'esp32':
    spi = SPI(1,
              baudrate=8_000_000,
              polarity=0,
              phase=0,
              sck=Pin(12),
              mosi=Pin(11),
              miso=Pin(13))
    ss  = Pin(10, Pin.OUT, value=1)
    en  = Pin(5, Pin.OUT)
    pwr = Pin(4, Pin.OUT)

# Shared flashing logic
def flash_fpga(filename):
    """Flash a bitstream to the FPGA via SPI."""
    pwr.value(0)
    time.sleep_ms(10)
    pwr.value(1)
    time.sleep_ms(10)

    with open(filename, 'rb') as f:
        data = f.read()

    ss.value(0)
    spi.write(data)
    ss.value(1)

    print(f"Flashed {len(data)} bytes from {filename}")
```

### Pattern 4 — Feature Detection at Runtime

For optional features like Wi-Fi on ESP32:

```python
import sys

def has_wifi():
    """Check if the current platform supports Wi-Fi."""
    try:
        import network
        return hasattr(network, 'WLAN')
    except ImportError:
        return False

# Usage
if has_wifi():
    import network
    wlan = network.WLAN(network.STA_IF)
    wlan.active(True)
    print("Wi-Fi available")
else:
    print("Wi-Fi not available on this board")
```

**Why `try/except` instead of `sys.platform`?** It's more Pythonic and future-proof. If a new board supports Wi-Fi, this code works automatically without adding another `elif`.

### Pattern 5 — Platform Config Module (Advanced)

For complex projects, extract the config into a shared module:

```
firmware/
└── micropython/
    ├── uart_sum.py
    └── shrike_config.py
```

**shrike_config.py:**
```python
"""
Platform configuration for the Shrike family.
Auto-detects the board and exports the correct pin mappings.
"""

import sys

_CONFIGS = {
    'rp2': {
        'platform':      'RP2040/RP2350',
        'spi_id':        0,
        'fpga_spi_ss':   1,
        'fpga_spi_sck':  2,
        'fpga_spi_mosi': 3,
        'fpga_spi_miso': 0,
        'fpga_en':       13,
        'fpga_pwr':      12,
        'uart_id':       0,
        'uart_tx':       0,
        'uart_rx':       1,
        'interconnect':  [6, 7, 8, 9, 10, 11],
    },
    'esp32': {
        'platform':      'ESP32-S3',
        'spi_id':        1,
        'fpga_spi_ss':   10,
        'fpga_spi_sck':  12,
        'fpga_spi_mosi': 11,
        'fpga_spi_miso': 13,
        'fpga_en':       5,
        'fpga_pwr':      4,
        'uart_id':       1,
        'uart_tx':       17,
        'uart_rx':       18,
        'interconnect':  [35, 36, 37, 38, 39, 40],
    },
}

if sys.platform not in _CONFIGS:
    raise RuntimeError(
        f"Unsupported platform: {sys.platform}. "
        f"Expected one of: {list(_CONFIGS.keys())}"
    )

board = _CONFIGS[sys.platform]
```

**uart_sum.py:**
```python
from shrike_config import board
from machine import UART, Pin

print(f"Running on {board['platform']}")

uart = UART(board['uart_id'],
            baudrate=115200,
            tx=Pin(board['uart_tx']),
            rx=Pin(board['uart_rx']))

# Clean application code — no platform checks needed
while True:
    if uart.any():
        data = uart.read()
        # process data ...
```

> **When to use this:** When multiple scripts in the same project all need
> platform config. For single-file examples, keep the config inline.

---

## Guidelines for Shrike Contributors

### When Writing a New Example

1. Start with the pin config block at the top (Pattern 1 for either language)
2. Keep all `#ifdef` / `sys.platform` checks in ONE place — don't scatter them
3. Use the `#else #error` / `raise RuntimeError` pattern to catch unsupported boards
4. Test on at least RP2040 + ESP32 before submitting (or note which boards are tested)
5. If the firmware is truly identical across boards (no pin differences), skip the platform block entirely

### When the Differences Are Too Large

Sometimes the firmware for RP2040 and ESP32 diverges significantly — different libraries, different APIs, different architecture. In that case, don't force a single file. Split into separate files:

```
firmware/
├── arduino-ide
│   ├── uart_sum_rp2040.ino
│   └── uart_sum_esp32.ino
└── micropython
    ├── uart_sum_rp2040.py
    └── uart_sum_esp32.py
```

**The rule of thumb:** If more than 40% of the code is inside `#ifdef` blocks, the "platform-agnostic" file is harder to read than two separate files. Split it.

### Decision Flowchart

```
Does the firmware differ between RP2040 and ESP32?
│
├── No  → Single file, no platform block needed
│
├── Only pin numbers differ
│   → Single file + Pattern 1 (pin config block)
│
├── Pin numbers + peripheral init differ
│   → Single file + Pattern 2 (pin config + init block)
│
├── Significant logic differences (>30% of code)
│   → Separate files per board
│
└── Shared config needed across multiple scripts
    → Extract into shrike_platform.h or shrike_config.py
```

---

## Quick Reference

### Arduino — Common Macros

| Macro | When Defined |
|---|---|
| `ARDUINO_ARCH_RP2040` | RP2040 and RP2350 (arduino-pico core) |
| `PICO_RP2350` | RP2350 only |
| `ARDUINO_ARCH_ESP32` | All ESP32 variants |
| `ARDUINO_ESP32S3_DEV` | ESP32-S3 specifically |

### MicroPython — Platform Strings

| String | When Returned by `sys.platform` |
|---|---|
| `'rp2'` | RP2040 and RP2350 |
| `'esp32'` | All ESP32 variants |

### Pin Mapping Reference

| Function | Shrike-Lite (RP2040) | Shrike (RP2350) | Shrike-fi (ESP32-S3) |
|---|---|---|---|
| SPI SS | 1 | 1 | 10 |
| SPI SCK | 2 | 2 | 12 |
| SPI MOSI | 3 | 3 | 11 |
| SPI MISO | 0 | 0 | 13 |
| FPGA EN | 13 | 13 | 5 |
| FPGA PWR | 12 | 12 | 4 |

---

## Summary

The Shrike family shares the same FPGA. The only firmware differences are pin mappings and peripheral initialization on the host MCU. By isolating these differences into a clearly marked configuration block at the top of each file, you get:

- **One file to maintain** instead of two or three
- **Consistent behavior** across the entire Shrike family
- **Easy onboarding** — contributors see the pattern once and can replicate it
- **Future-proof** — when Shrike-fi ships, existing examples just need a pin block added

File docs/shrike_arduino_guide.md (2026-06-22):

(shrike_arduino_guide)=

# Using Shrike With ArduinoIDE

If you are someone who is familiar with arduino and its infrastructure and don't want to move away to micro-python no worries we have got you cover.

These are the steps you can follow make arduino IDE usable with shrike.

Now before starting you should know that you will still need to use the Renesas Go configure software hub for generating firmware for fpga however all the other task can be done from arduino ide. 

Now we will follow these steps to setup our arduino IDE for shrike. If you don't have arduino IDE already ,you can download it from [here](https://www.arduino.cc/en/software/) or if you are using linux(ubuntu)then just run 
```
sudo apt install arduino
```

### Step 1. Adding the board support for RP2350/RP2040

The Shrike has a on board RP2350/RP2040 has a host controller the Arduino IDE doesn't native support them however we can add the board support for the same. 
It is quit straight forward we need to add this URL 
```
https://github.com/earlephilhower/arduino-pico/releases/download/global/package_rp2040_index.json
``` 
in the addition board URL section of arduino IDE which you can find in File->Preferences.

<div align="center">

 ADD BOARD URL

</div>

If you already have another board URL just add a "," between the two URL's.

These board support had been created by [earlephilhower](https://github.com/earlephilhower) and you can check out github [repository](https://github.com/earlephilhower/arduino-pico) for more details.

After adding the URL go to Tools->Boards->Board Manager in the Arduino IDE. 
Then search for pico and the board from Earle F. Philhower. 

<div align="center">

 ADD BOARD

</div>
Perfect we have successfully add the board support for the RP2040/RP2350.

### Step 2. Adding the Little-FS Tool 

Now we need to add a Little-FS utility to bind a bin file (FPGA bitstream with code for Shrike). We can find the utility [here](https://github.com/earlephilhower/arduino-pico-littlefs-plugin/releases/) download the latest release ZIP. 

Now we need to unzip and copy it to the tools directory in Arduino directory.

In case of windows you will find the Arduino folder in C disk if you have not changed it during installation.
In case of linux it would be available in your home directory. 

The directory/ folder  should look like this `<home_dir>/Arduino/tools/PicoLittleFS/tool/picolittlefs.jar`

Now you will need to restart the Arduino IDE and you should see the Pico Little FS tool like this in your Tools menu.

For more details on the PicoLittleFS tool checkout this [repository](https://github.com/earlephilhower/arduino-pico-littlefs-plugin).

### Step 3. Installing the Shrike Library 

Now we need to add the Shrike Library in arduino to do so go to library manager in arduino IDE and search Shrike and install the Shrike library.

<div align="center">

 ADD SHRIKE lib

</div>

Choose the first one names as Shrike and not the shrike flash library.
We are almost done with the setup lets continue and blink en led on FPGA using the arduino IDE. 

### Step 4. Programming the FPGA from ArduinoIDE
Lets program out first bitstream to fpga using the arduino. We will be blinking an led.

StartArduino IDE and look for Shrike >- shrike_flash in the example section of IDE and then save it with a name of you choice and at a location of your choice. This will create a folder with the name, now in the folder/dir create a subfolder by name `data` keep the case and in mind. 

Any bitstream that needs to be uploaded to the board should be placed in the folder. 
We have already generated and hosted a bitstream to blink led [here](https://github.com/vicharak-in/shrike/blob/main/test/bitstreams/v1_4/led_blink.bin) save this bitstream to the data subfolder.

Checkout guide to learn how to generate your own fpga design [here](./generating_your_first_bitstream.md).

Onces you have done this go to arduino and hit compile your compilation should finish without error if error occurs don't we have s discord hope on there. 

If the compilation has been done without any error then it's time to connect the board in boot mode " PRESS THE BOOT BUTTON WHILE CONNECTING THE BOARD WITH PC" ( this should be done only the first time of setting up if arduino are if you have programmed the board with any other way last time).

And then hit upload on the board. 

You should see the beautiful blue led blinking on board.

Congratulation you have you arduino IDE and shrike ready to programmed using the Arduino infrastructure. 

>Credit and Gratitude  to [earlephilhower](https://github.com/earlephilhower/) to creating the board support for RP2040/RP2350 in ArduinoIDE and the little FS tool.

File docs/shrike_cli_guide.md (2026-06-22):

(shrike_cli_guide)=

# User guide to access and use shrike from your terminal(CLI)

If you are anything like our team at [vicharak](vicharak.in) and you don't want to move away from the terminal. We have got you cover here is a quick guide for accessing and using shrike from terminal (CLI). 

To do so we will be using mpremote feature of micro-python.

Before getting started with accessing the shrike over terminal you should upload the shrike uf2 board read first two steps from [this](./getting_started.md) guide to learn how to. 

Now we are assuming that you have done those two steps lets connect with shrike over terminal.

We will follow these steps 

### 1. Getting the Py-env and mpremote

Mpremote is a python package and we will have to use pip to install it thus we need to a py virtual env. (if you already have one use that).

Or to setup a python Env read [this](https://docs.python.org/3/library/venv.html) and then activate it . 

Now that your v-env is activated we will get mpremote in the env. To do so run this command 

```
    pip install mpremote 
```
if everything run's without error you have successfully got all the tools to access shrike over terminal however if you face issues then google it or ask in our discord. 

Now lets blink led from the terminal 

### 2. Blinking the CPU led 

To check out how mpremote works we will first blink the led connected to rp2040/rp2350 and then we will flash blink_led bitstream on fpga.

To blink a led on rp2040/rp2350 the python script looks like this save this as a test_led.py file on your pc.

```
from machine import Pin
import time

led = Pin(4, Pin.OUT)  # onboard LED on GPIO 25

while True:
led.toggle()   # switch state
time.sleep(0.5)
```
then we can run this file using the command 
```
    mpremote run test_led.py
```

if you have multiple shrike or rp2040 connected then you need to specify the port number of the board you want to programme something like 

```
    mpremote connect port:<port path> run test_led.py
```
you should see the led blinking on shrike.

You can also access the REPL on the rp2040 by running 

```
    mpremote 
```
now you can python one line at a time. 

### 3. Uploading the bitstream to the shrike.

To flash the fpga with bitstream we need to first upload it to the rp2040 to do that we need to simply run the cp command of mpremote. The bitstream file could be found [here](https://github.com/vicharak-in/shrike/tree/main/test/bitstreams/) get the one corresponding to your board version. 

```
    mpremote cp blink_led.bin : 
```
do not forget the : in the end . Now just run the cmd below to check if the file is copied or not
```
    mpremote ls 
```
lets flash that bitstream to the fpga now.

### 4. Flashing the fpga 

To flash the uploaded bitstream we need to execute this python script 

```
import shrike

#shrike.flash("<bitstream_name>.bin")
# in our case that is 

shrike.flash("blink_led.bin")
```
now you can run this cmd as mentioned in step 2 or you can open the repl and type the python script one by one.

Onces the fpga is flashed you should see the led connected to fpga blinking.

The mpremote has a lot more features as well you can check them all out in there guide [here](https://docs.micropython.org/en/latest/reference/mpremote.html#).

Will also suggest reading this [discussion](https://github.com/orgs/micropython/discussions/9096).

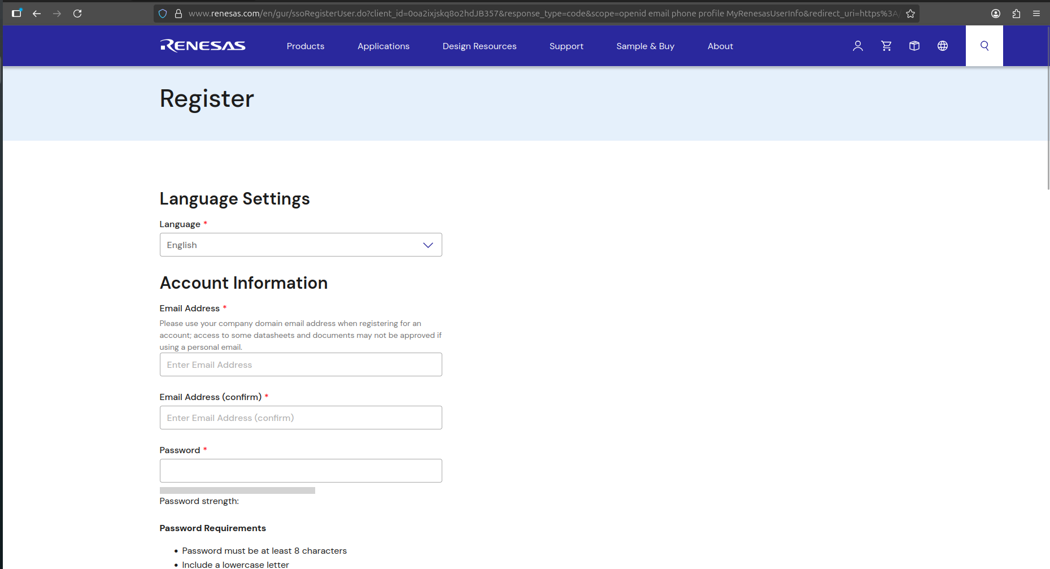
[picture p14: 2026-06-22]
docs/images/tools_setup/renesas_register.png

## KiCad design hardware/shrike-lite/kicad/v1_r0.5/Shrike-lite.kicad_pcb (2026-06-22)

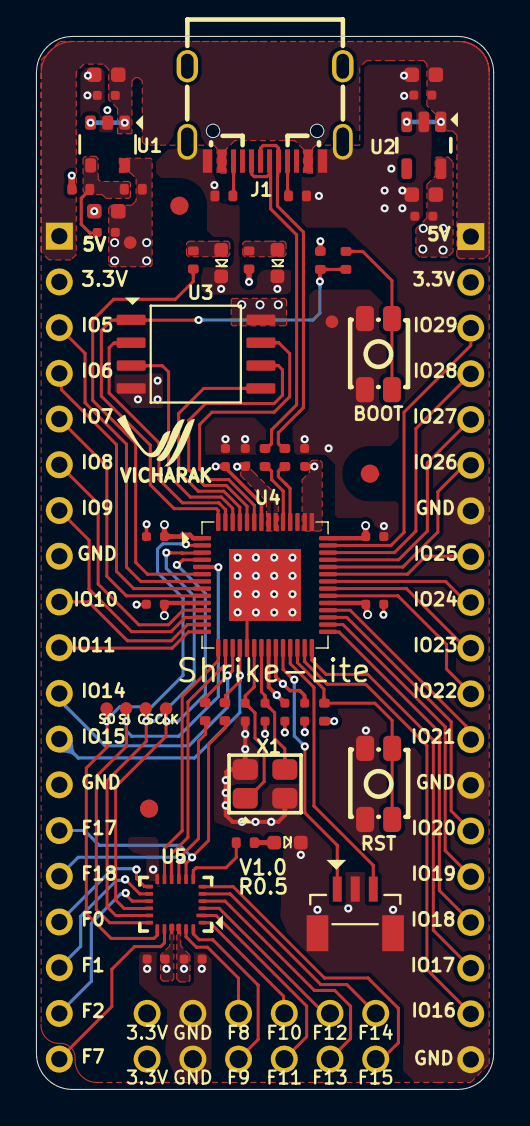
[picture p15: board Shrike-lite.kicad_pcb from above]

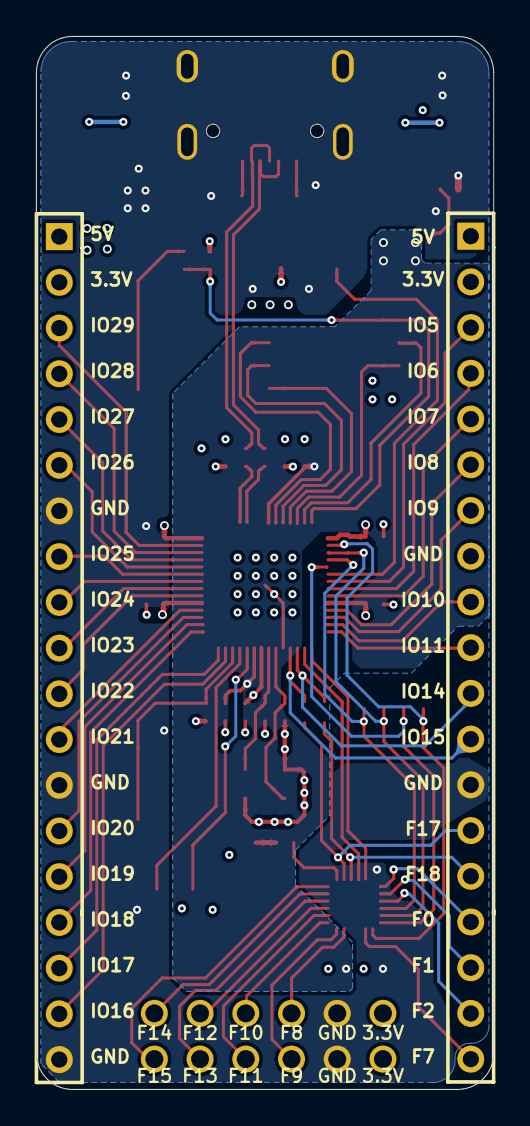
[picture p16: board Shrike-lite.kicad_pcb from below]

Board: 4 copper layers, 25.4 x 58.5 mm, 57 parts (2 on the bottom side), 71 nets.

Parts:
2: TP
C1, C3, C5, C8: 100nF 10V; Cap_0603
C2, C4, C6, C7, C9, C10, C11, C12, C13, C14, C15, C16, C17, C18, C19, C20, C21: Cap_0402
CLK: TP
CS: TP
D1: LED1; LED_0603
D2, D3: LED_0603
GND1: TP
J1: Type-C
J2, J4: Header 19X1_2.54MM; 1X19_HEADER
J3: DNP; 2X6_HEADER
J5: XUNPU WAFER-SH1.0-3PLB
R1: RES_0402_5; Res_0402
R2, R3, R4, R5, R6, R7, R8, R9, R10, R11, R12, R13, R14: Res_0402
SI: TP
SO: TP
SW1: SW PUSHBUTTON; SW_MICRO PUSH BUTTON 4 PAD
SW2: SW PUSHBUTTON; Switch
U1: SOT23-5
U2: SOT25
U3: SOIC-8
U4: RP2040; QFN_56
U5: QFN_24
X1: CRYSTAL_3225

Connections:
1.1V: 2.1, C7.2, C8.2, C11.1, C12.1, C20.1, R4.1, U1.5, U4.23, U4.50, U5.22
3.3V: C3.2, C4.2, C13.1, C14.1, C15.1, C16.1, C17.1, C18.1, C19.1, C21.1, J2.2, J3.1, J3.2, J4.2, R1.1, R9.1, R10.2, U2.5, U3.8, U4.1, U4.10, U4.22, U4.33, U4.42, U4.43, U4.44, U4.48, U4.49, U5.21
BOOT: R11.2, SW2.1, SW2.2
CS0: R9.2, R11.1, U3.1, U4.56
CS1: CS.1, U4.3, U5.17
EN: U4.16, U5.10
F_GPIO0: J2.16, U5.13
F_GPIO1: J2.17, U5.14
F_GPIO2: J2.18, U5.15
F_GPIO7: J2.19, U5.20
F_GPIO8: J3.6, U5.23
F_GPIO9: J3.5, U5.24
F_GPIO10: J3.8, U5.1
F_GPIO11: J3.7, U5.2
F_GPIO12: J3.10, U5.3
F_GPIO13: J3.9, U5.4
F_GPIO14: J3.12, U5.5
F_GPIO15: J3.11, U5.6
F_GPIO16: R6.1, U5.7
F_GPIO17: J2.14, R8.2, U5.8
F_GPIO18: J2.15, R7.2, U5.9
F_SPI_CLK: CLK.1, U4.4, U5.16
F_SPI_SI: SI.1, U4.5, U5.18
F_SPI_SO: SO.1, U4.2, U5.19
GND: C1.1, C2.1, C3.1, C4.1, C5.1, C6.1, C8.1, C9.2, C10.2, C11.2, C12.2, C13.2, C14.2, C15.2, C16.2, C17.2, C18.2, C19.2, C20.2, C21.2, D1.K, D2.K, D3.K, GND1.1, J1.A1, J1.A12, J1.S1, J1.S2, J1.S3, J1.S4, J2.8, J2.13, J3.3, J3.4, J4.7, J4.13, J4.19, J5.2, J5.4, J5.5, R2.2, R3.2, R5.2, SW1.3, SW1.4, SW2.3, SW2.4, U1.2, U2.2, U3.4, U4.19, U4.57, U5.12, X1.2, X1.4
GPIO4: R14.1, U4.6
GPIO5: J2.3, U4.7
GPIO6: J2.4, U4.8
GPIO7: J2.5, U4.9
GPIO8: J2.6, U4.11
GPIO9: J2.7, U4.12
GPIO10: J2.9, U4.13
GPIO11: J2.10, U4.14
GPIO14: J2.11, R7.1, U4.17
GPIO15: J2.12, R8.1, U4.18
GPIO16: J4.18, U4.27
GPIO17: J4.17, U4.28
GPIO18: J4.16, U4.29
GPIO19: J4.15, U4.30
GPIO20: J4.14, U4.31
GPIO21: J4.12, U4.32
GPIO22: J4.11, U4.34
GPIO23: J4.10, U4.35
GPIO24: J4.9, U4.36
GPIO25: J4.8, U4.37
GPIO26: J4.6, U4.38
GPIO27: J4.5, U4.39
GPIO28: J4.4, U4.40
GPIO29: J4.3, U4.41
HOLD: U3.7, U4.51
NetC7_1: C7.1, R4.2, R5.1, U1.4
NetD1_A: D1.A, R1.2
NetD2_A: D2.A, R6.2
NetD3_A: D3.A, R14.2
NetJ1_A5: J1.A5, R3.1
NetJ1_B5: J1.B5, R2.1
PWR: U4.15, U5.11
RUN: R10.1, SW1.1, SW1.2, U4.26
SPI_CLK: U3.6, U4.52
SPI_SI: U3.5, U4.53
SPI_SO: U3.2, U4.55
SWCLK: J5.1, U4.24
SWD: J5.3, U4.25
USB_N: J1.A7, J1.B7, R12.1
USB_P: J1.A6, J1.B6, R13.1
USBx_N: R12.2, U4.46
USBx_P: R13.2, U4.47
VUSB: C1.2, C2.2, C5.2, C6.2, J1.A4, J1.A9, J2.1, J4.1, U1.1, U1.3, U2.1, U2.3
WP: U3.3, U4.54
XIN: C9.1, U4.20, X1.1
XOUT: C10.1, U4.21, X1.3

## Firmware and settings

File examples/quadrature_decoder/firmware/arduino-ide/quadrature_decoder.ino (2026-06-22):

/**
 * Example: Quadrature Decoder on Shrike-Lite (FPGA + RP2040)
 *
 * This sketch demonstrates how to:
 *  - Load a quadrature_decoder bitstream into the Shrike FPGA
 *  - Read the UART packets come from FPGA (Tx) on an RP2040 Rx pin
 *  - Print the status of Position, Speed, Angle and Direction over Serial
 *
 * Hardware mapping (from Shrike pinouts):
 *  - FPGA PIN4 (Tx) → RP2040 GPIO 1 (Rx)
 *
 */

#include "Arduino.h"
#include "Shrike.h"

// -----------------------------------------------------------------------------
// Bitstream configuration
// -----------------------------------------------------------------------------

/**
 * Path to the FPGA bitstream.
 *
 * Make sure:
 *  - The file is present in your project / filesystem
 *  - The path matches your environment
 */
#define BITSTREAM "/quadrature_decoder.bin"

// -----------------------------------------------------------------------------
// Pin definition of UART Rx and Baudrate configuration
// -----------------------------------------------------------------------------

/**
 * UART_RX
 * ----------
 * This is the RP2040 pin that receives the UART packet from the FPGA Tx.
 * Baudrate can configure here. Baudrate should be same on both sides. 
 * (FPGA side and RP2040 side).
 * ----------
 */
#define RX_PIN 1
#define BAUDRATE 115200

// -----------------------------------------------------------------------------
// FPGA flashing
// -----------------------------------------------------------------------------

/**
 * ShrikeFlash
 * -----------
 * This object handles communication with the Shrike board's flash and FPGA.
 * We will:
 *  - Initialize it in setup()
 *  - Use it to flash (load) the quadrature_decoder bitstream into the FPGA
 */
ShrikeFlash shrike;

// -----------------------------------------------------------------------------
// FEATURE TOGGLE for Dummy Encoder signals
// -----------------------------------------------------------------------------
/**
 * Internal Encoder Test Mode
 * -----------
 * If you don't have encoder sensors, you can generate dummy signals
 * using RP2040 GPIO pins for testing the FPGA decoder.
 * Sets GPIO pins as outputs for dummy encoder signals :
 *     - 1 = internal encoder signal generator (for testing FPGA)
 *     - 0 = real encoder / external signals used
 * 
 */
#define USE_INTERNAL_ENCODER_TEST 1

// -----------------------------------------------------------------------------
// Pins definition of dummy encoder signals on shrike
// -----------------------------------------------------------------------------

/**
 * ENC_A_PIN and ENC_B_PIN
 * ----------
 * These are the RP2040 pins outputs the generated dummy signals.
 * ----------
 */
#define ENC_A_PIN 17
#define ENC_B_PIN 18

// -----------------------------------------------------------------------------
// Uart Packet Handling
// -----------------------------------------------------------------------------

/**
 * Fpga will send the packet of 8 bytes which is in the below format.
 * - [AA][pos MSB][pos LSB][spd MSB][spd LSB][ang MSB][ang LSB][dir]
 * 
 * AA  - Header, pos - Position (16bits), spd - Speed (16-bits)
 * ang - Angle (16-bits), dir - Direction (8-bits)
 *
 * The packet is decoded after receiving data from FPGA.
*/
uint8_t packet[8];
uint8_t idx = 0;
bool receiving = false;

// -----------------------------------------------------------------------------
// Timing counter used in Dummy encoder signals generation
// -----------------------------------------------------------------------------
unsigned long last_encoder_tick = 0;

// -----------------------------------------------------------------------------
//  ENCODER TEST MODE
// -----------------------------------------------------------------------------
/**
 * Creates quadrature waveform. They are 90° phase shifted.
 * The order of transitions determines direction :
 *     - 00 → 01 → 11 → 10 → repeat (Forward Rotation Pattern)
 *     - 00 → 10 → 11 → 01 → repeat (Reverse Rotation Pattern)
 * Simulates rotation and Feeds FPGA inputs
 * Generates the forward and reverse direction sequences
 * and that diresction will toggles for every 5 sec.
 * This is ONLY for testing FPGA without real encoder
 *
*/
#if USE_INTERNAL_ENCODER_TEST

uint8_t enc_state = 0;
bool direction = true;

void init_encoder_test() {
    pinMode(ENC_A_PIN, OUTPUT);
    pinMode(ENC_B_PIN, OUTPUT);
}

void generate_encoder() {

    // speed control (~500 Hz step rate)
    if (millis() - last_encoder_tick < 2) return;
    last_encoder_tick = millis();

    // optional direction toggle every ~5 sec
    if ((millis() / 5000) % 2 == 0)
        direction = true;
    else
        direction = false;

    if (direction) {
        switch (enc_state) {
            case 0: digitalWrite(ENC_A_PIN, LOW);  digitalWrite(ENC_B_PIN, LOW);  break;
            case 1: digitalWrite(ENC_A_PIN, HIGH); digitalWrite(ENC_B_PIN, LOW);  break;
            case 2: digitalWrite(ENC_A_PIN, HIGH); digitalWrite(ENC_B_PIN, HIGH); break;
            case 3: digitalWrite(ENC_A_PIN, LOW);  digitalWrite(ENC_B_PIN, HIGH); break;
        }
    } else {
        switch (enc_state) {
            case 0: digitalWrite(ENC_A_PIN, LOW);  digitalWrite(ENC_B_PIN, LOW);  break;
            case 1: digitalWrite(ENC_A_PIN, LOW);  digitalWrite(ENC_B_PIN, HIGH); break;
            case 2: digitalWrite(ENC_A_PIN, HIGH); digitalWrite(ENC_B_PIN, HIGH); break;
            case 3: digitalWrite(ENC_A_PIN, HIGH); digitalWrite(ENC_B_PIN, LOW);  break;
        }
    }

    enc_state = (enc_state + 1) & 0x03;
}

#endif

// -----------------------------------------------------------------------------
// SET UP Block
// -----------------------------------------------------------------------------

void setup() {

    Serial.begin(115200);
    while (!Serial);

    Serial.println("Starting...");

    /**
     * Shrike / FPGA initialization
     * ----------------------------
     * 1. Initialize the Shrike interface
     * 2. Load the quadrature_decoder bitstream into the FPGA
     *
     * After shrike.flash(), the FPGA should be running the decoder logic,
     * and its output is routed to Uart Rx pin of RP2040.
     */
    shrike.begin();
    shrike.flash(BITSTREAM);

    Serial.println("FPGA Flash Done");

    delay(2000);

    // UART from FPGA
    Serial1.setRX(RX_PIN);
    Serial1.begin(BAUDRATE);

    Serial.println("UART Ready");

#if USE_INTERNAL_ENCODER_TEST
    init_encoder_test();
#endif
}

// -----------------------------------------------------------------------------
// LOOP block
// -----------------------------------------------------------------------------
/*
 * UART Packets receving and Decoding happens here and prints over serial monitor.
 * Reads incoming FPGA bytes continuously.
 * Multi-byte fields are transmitted MSB first (big-endian format).
 * Ensures correct alignment using header and followed by 7 bytes of data
 *     - [AA][pos MSB][pos LSB][spd MSB][spd LSB][ang MSB][ang LSB][dir]
 *
 * For Position and Speed decoding :
 *     - Combines 2 bytes → signed 16-bit and decides the +ve or -ve based on sign
 *     - Position and speed are signed values.
 *     - Positive  -> forward rotation
 *     - Negative  -> reverse rotation
 * For Angle : FPGA gives encoder counts, so convert to degrees 
 * 4000 CPR means one full mechanical rotation produces 4000 quadrature counts.
 * For Direction byte : Only LSB will decide
 *     - 1 = forward
 *     - 0 = reverse
 *
*/
void loop() {

#if USE_INTERNAL_ENCODER_TEST
    generate_encoder();
#endif

    while (Serial1.available()) {

        uint8_t b = Serial1.read();

        // sync on header
        if (!receiving) {
            if (b == 0xAA) {
                receiving = true;
                idx = 0;
                packet[idx++] = b;
            }
            continue;
        }

        packet[idx++] = b;

        if (idx == 8) {
            receiving = false;

            // decode signed values
            int16_t position = (int16_t)((int16_t(packet[1]) << 8) | packet[2]);
            int16_t speed    = (int16_t)((int16_t(packet[3]) << 8) | packet[4]);
            uint16_t angle   = (uint16_t)((packet[5] << 8) | packet[6]);
            uint8_t direction = packet[7] & 0x01;

            float angle_deg = ((float)angle * 360.0f) / 4000.0f;

            Serial.print("Pos: ");
            Serial.print(position);

            Serial.print(" | Spd: ");
            Serial.print(speed);

            Serial.print(" | Ang: ");
            Serial.print(angle_deg);

            Serial.print(" deg | Dir: ");
            Serial.println(direction ? "FWD" : "REV");
        }
    }
}

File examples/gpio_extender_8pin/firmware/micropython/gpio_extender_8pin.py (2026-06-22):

from machine import Pin, SPI
import time

# --- Hardware Configuration ---
# Based on your confirmed mapping
sck_pin  = Pin(2)
mosi_pin = Pin(3)
miso_pin = Pin(0)
ss_pin   = Pin(1, Pin.OUT, value=1)
rst_pin  = Pin(14, Pin.OUT, value=1)

# Probe pin to read physical FPGA output
probe = Pin(15, Pin.IN) 

# SPI0 Initialization (CPOL=0, CPHA=0)
spi = SPI(0, baudrate=1_000_000, sck=sck_pin, mosi=mosi_pin, miso=miso_pin)

# --- Register Addresses (From Verilog Case Statement) ---
ADDR_DIR_LOW  = 0x1 # gpio_dir_reg[3:0]
ADDR_DIR_HIGH = 0x2 # gpio_dir_reg[7:4]
ADDR_OUT_LOW  = 0x3 # gpio_out_reg[3:0]
ADDR_OUT_HIGH = 0x4 # gpio_out_reg[7:4]

def send_cmd(addr, data):
    """Sends command and returns the current physical state of the 8 GPIOs"""
    packet = (addr << 4) | (data & 0x0F)
    ss_pin.value(0)
    # The MISO return value reflects i_gpio_pins
    read_byte = spi.read(1, packet)[0]
    ss_pin.value(1)
    return read_byte

def reset_fpga():
    print("Action: Resetting FPGA Core...")
    rst_pin.value(0)
    time.sleep(0.1)
    rst_pin.value(1) # De-assertion synchronized internally
    time.sleep(0.1)

# --- Test Suite ---
def run_tests():
    reset_fpga()
    
    # TEST 1: Default State Verification
    # On reset, all pins should be Inputs (High-Z)
    initial_state = send_cmd(0x0, 0x0)
    print(f"Test 1: Reset State - Read: {bin(initial_state)} (Expected: All Inputs)")

    # TEST 2: Lower Nibble Output Drive
    print("\nTest 2: Lower Nibble (Pins 20, 23, 24, 1) Drive Test")
    send_cmd(ADDR_DIR_LOW, 0x0) # Set lower 4 bits to Output (0)
    print("Action: Connect Jumper from RP2040 GPIO 15 to FPGA Pin 20 (Bit 0)")
    
    for val in [0x1, 0x2, 0x4, 0x8]: # Walking 1s
        send_cmd(ADDR_OUT_LOW, val)
        time.sleep(0.1)
        # Physical check on Bit 0 (only if val is 0x1)
        if val == 0x1:
            print(f" - Bit 0 High Check: {'PASS' if probe.value() == 1 else 'FAIL'}")
        send_cmd(ADDR_OUT_LOW, 0x0) # Clear
        time.sleep(0.1)

    # TEST 3: Upper Nibble Independent Drive
    print("\nTest 3: Upper Nibble (Pins 2, 3, 4, 5) Drive Test")
    send_cmd(ADDR_DIR_HIGH, 0x0) # Set upper 4 bits to Output (0)
    print("Action: Move Jumper to FPGA Pin 2 (Bit 4)")
    
    send_cmd(ADDR_OUT_HIGH, 0x1) # Set Bit 4 High
    time.sleep(0.1)
    print(f" - Bit 4 High Check: {'PASS' if probe.value() == 1 else 'FAIL'}")
    
    # TEST 4: Persistence Check
    # Ensure writing upper nibble didn't overwrite lower nibble output state
    send_cmd(ADDR_OUT_LOW, 0x1) # Bit 0 High
    send_cmd(ADDR_OUT_HIGH, 0x8) # Bit 7 High
    # Both should now be high in the readback
    current_read = send_cmd(0x0, 0x0)
    print(f"Test 4: Persistence Read - {bin(current_read)} (Should see bits 0 and 7 High)")

    # TEST 5: Input Mode (Tristate) Verification
    print("\nTest 5: Tristate/Input Mode Check")
    send_cmd(ADDR_DIR_LOW, 0xF) # Set Lower to Input (1)
    print("Action: Connect FPGA Pin 20 to 3.3V")
    time.sleep(2) # Give user time to connect
    input_read = send_cmd(0x0, 0x0)
    print(f" - Pin 20 (Bit 0) High Input Detection: {'PASS' if (input_read & 0x01) else 'FAIL'}")

run_tests()
